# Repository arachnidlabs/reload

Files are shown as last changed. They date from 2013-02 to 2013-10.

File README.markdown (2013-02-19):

# Re:load #



Re:load is an adjustable dummy load with the following features:

 * No external power supply required - powered by the device under test.
 * Wide range of input voltages, from 3.3 to 30 volts.
 * Adjustable load from 0 to 3.5 amps (or 0 to 10 amps in the high current version)
 * Up to 14 watts power dissipation (40 watts in the high current version)
 * Virtually indestructible: The power FET, BTS117, has built in overtemp, ESD, and overcurrent protection. A diode protects the opamp from reverse bias.
 * Load remains constant under the whole range of input voltage.
 * Screw terminal and banana plug footprints.
 * Low BoM cost, and easy to solder thru-hole parts.
 * Test points for reading current with a voltmeter.
 
Read more about Re:load [here](http://www.arachnidlabs.com/reload/), buy the regular one [here](https://tindie.com/shops/arachnidlabs/reload-the-simple-robust-affordable-dummy-load/) and Epic Re:load [here](https://tindie.com/shops/arachnidlabs/epic-reload-the-simple-robust-powerful-adjustable-dummy-load/). Assembly and usage instructions can be found [here](http://www.arachnidlabs.com/reload/instructions.html).
 
## BoM ##

<table>
  <thead>
    <tr><th>Designation</th><th>Re:load Part</th><th>Epic Re:load part</th><th>Quantity</th></tr>
  </thead>
  <tr><th></th><td colspan="2">Re:load PCB</td><td>1</td></tr>
  <tr><th>Q1</th><td>BTS117 TO-220 MOSFET</td><td>BTS141 TO-220 MOSFET</td><td>1</td></tr>
  <tr><th></th><td>12 watt heatsink</td><td>20 watt heatsink</td><td>1</td></tr>
  <tr><th>R1</th><td colspan="2">3 watt 0.05 ohm resistor</td><td>1</td></tr>
  <tr><th>R6</th><td colspan="2">10k ohm potentiometer</td><td>1</td></tr>
  <tr><th>IC1</th><td colspan="2">MCP6002 8-DIP Op-Amp</td><td>1</td></tr>
  <tr><th>IC2</th><td colspan="2">LP2950 3.0v precision LDO regulator</td><td>1</td></tr>
  <tr><th>JP1</th><td colspan="2">2 terminal 5.0mm spring terminal</td><td>1</td></tr>
  <tr><th>D1</th><td colspan="2">BAT42 Schottky Diode</td><td>1</td></tr>
  <tr><th>C2</th><td colspan="2">33uF Electrolytic Capacitor</td><td>1</td></tr>
  <tr><th>C3</th><td colspan="2">1uF Ceramic Capacitor</td><td>1</td></tr>
  <tr><th>C1</th><td colspan="2">0.1uF Ceramic Capacitor</td><td>1</td></tr>
  <tr><th rowspan="3">R3</th><td colspan="2">510k ohm resistor</td><td>1</td></tr>
  <tr><td colspan="2">160k ohm resistor</td><td>1</td></tr>
  <tr><td colspan="2">75k ohm resistor</td><td>1</td></tr>
  <tr><th>R4, R5</th><td colspan="2">10k ohm 1% resistor</td><td>2</td></tr>
  <tr><th>R7</th><td colspan="2">100 ohm resistor</td><td>1</td></tr>
  <tr><th></th><td colspan="2">Packet of thermal paste</td><td>1</td></tr>
  <tr><th></th><td colspan="2">M3 6mm machine screw</td><td>1</td></tr>
  <tr><th></th><td colspan="2">M3 nut</td><td>1</td></tr>
</table>

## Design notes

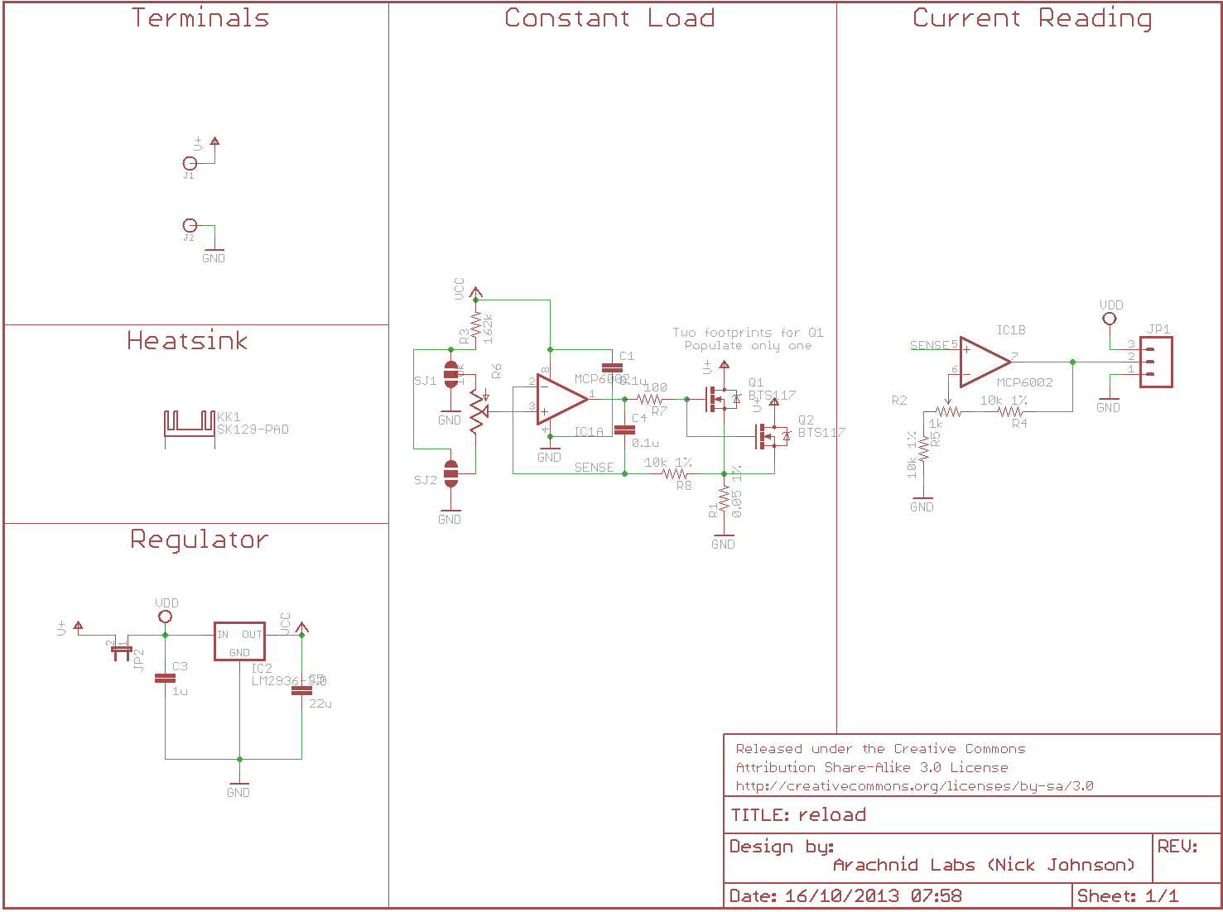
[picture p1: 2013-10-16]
reload-schematic.png

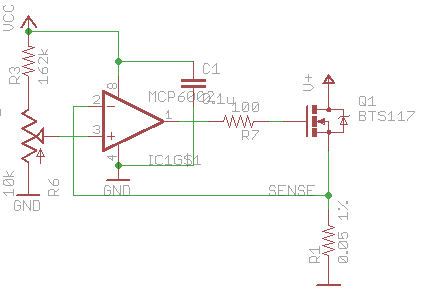
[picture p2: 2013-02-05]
reload-core-schematic.png

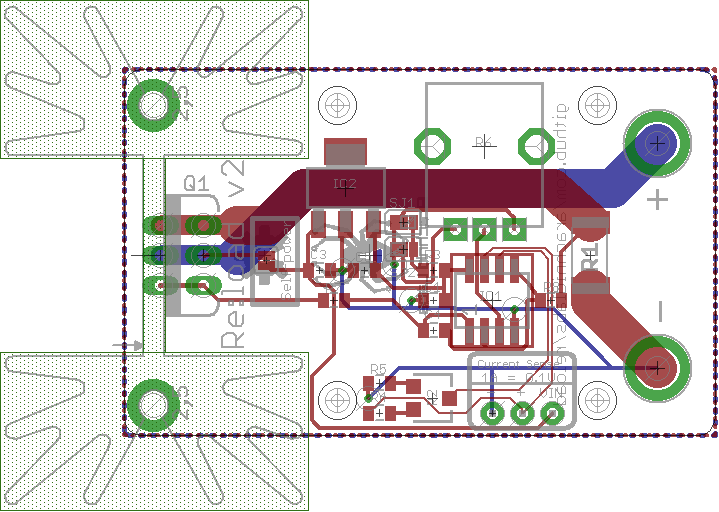
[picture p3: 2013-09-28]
reload-layout.png

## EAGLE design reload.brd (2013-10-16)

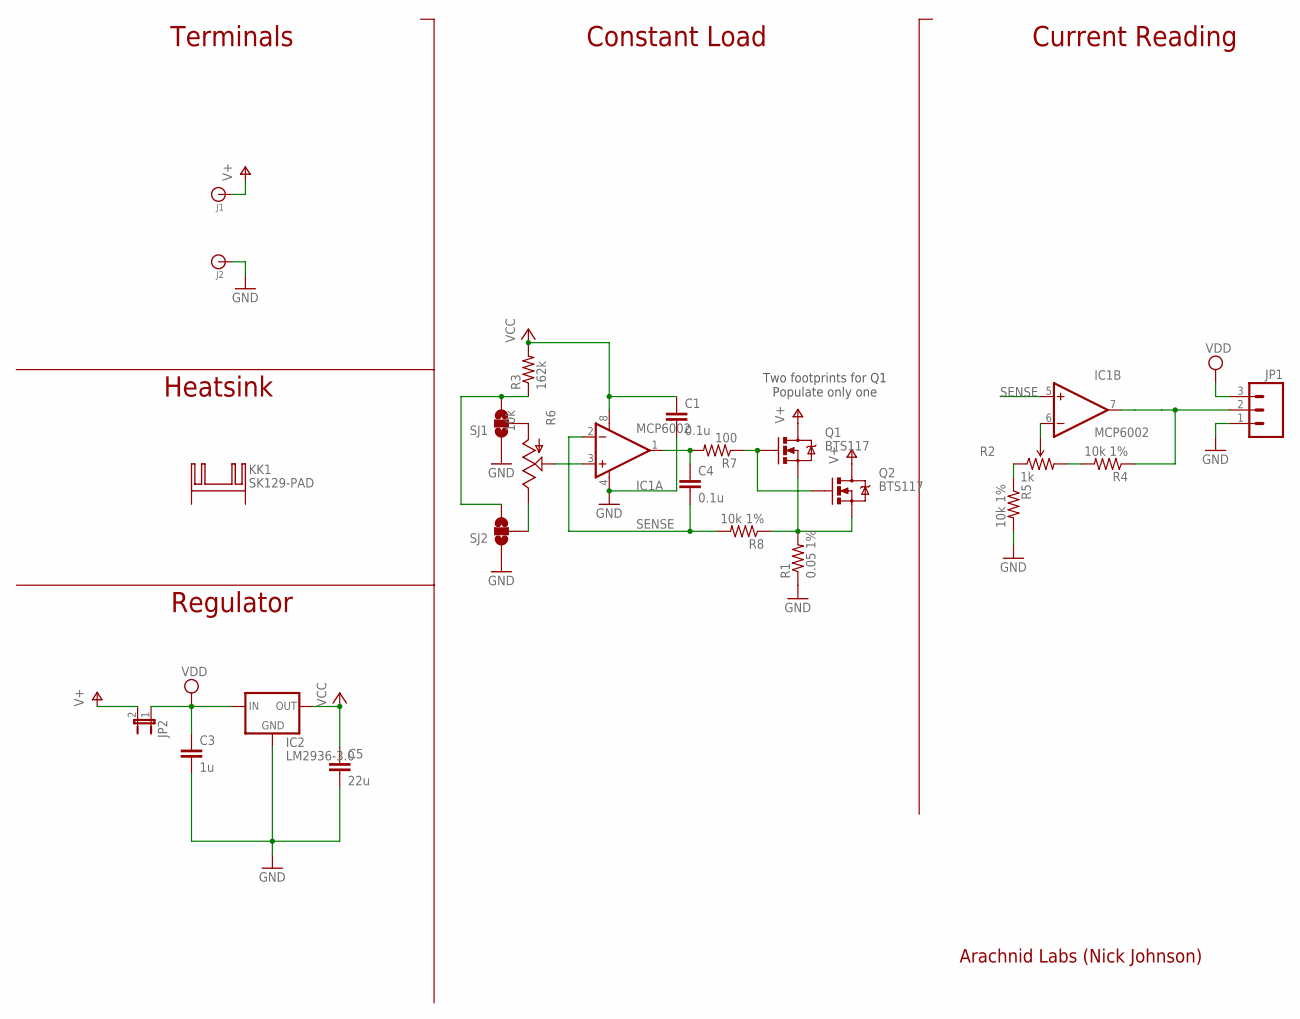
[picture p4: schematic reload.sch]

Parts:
C1, C4: 0.1u; 0805
C3: 1u; 0805
C5: 22u; 0805
IC1: MCP6002; SOP08
IC2: LM2936-3.0; SOT223
J1, J2: BANANA_CONN
JP1: M031X03_NO_SILK; 1X03_NO_SILK
JP2: JUMPER-2SMD-NC; SJ_2S
KK1: SK129-PAD; SK129
Q1: BTS117; TO220V
Q2: BTS117; TO220V-NOSILK
R1: 0.05 1%; R2512
R2: 1k; TRIMPOT-EVN5E
R3: 162k; 0805
R4, R5, R8: 10k 1%; 0805
R6: 10k; ALPS_POT
R7: 100; 0805
SJ1: SOLDERJUMPER_2WAYPASTE2&3; SJ_3_PASTE2&3
SJ2: SOLDERJUMPER_2WAYPASTE1&2; SJ_3_PASTE1&2

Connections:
GND: C1.2, C3.2, C5.2, IC1.4 (V-), IC2.2 (GND), J2.P$1, JP1.1, R1.1, R5.2, SJ1.1, SJ2.1
IREF: IC1.7 (OUT), JP1.2, R4.1
unnamed: C4.1, IC1.1 (OUT), R7.2
unnamed: R6.P$3 (A), SJ1.2
unnamed: Q1.3 (S), Q2.3 (S), R1.2, R8.1
unnamed: IC1.3 (+IN), R6.P$2 (S)
unnamed: IC1.6 (-IN), R2.2 (WIPER)
unnamed: R2.1 (CCW), R5.1
unnamed: R2.3 (CW), R4.2
unnamed: R6.P$1 (E), SJ2.2
unnamed: Q1.1 (G), Q2.1 (G), R7.1
unnamed: R3.1, SJ1.3, SJ2.3
SENSE: C4.2, IC1.2 (-IN), IC1.5 (+IN), R8.2
V+: J1.P$1, JP2.2, Q1.2 (D), Q2.2 (D)
VCC: C1.1, C5.1, IC1.8 (V+), IC2.3 (OUT), R3.2
VDD: C3.1, IC2.1 (IN), JP1.3, JP2.1

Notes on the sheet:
Terminals
Heatsink
Regulator
Constant Load
Current Reading
Arachnid Labs (Nick Johnson)
Two footprints for Q1 Populate only one

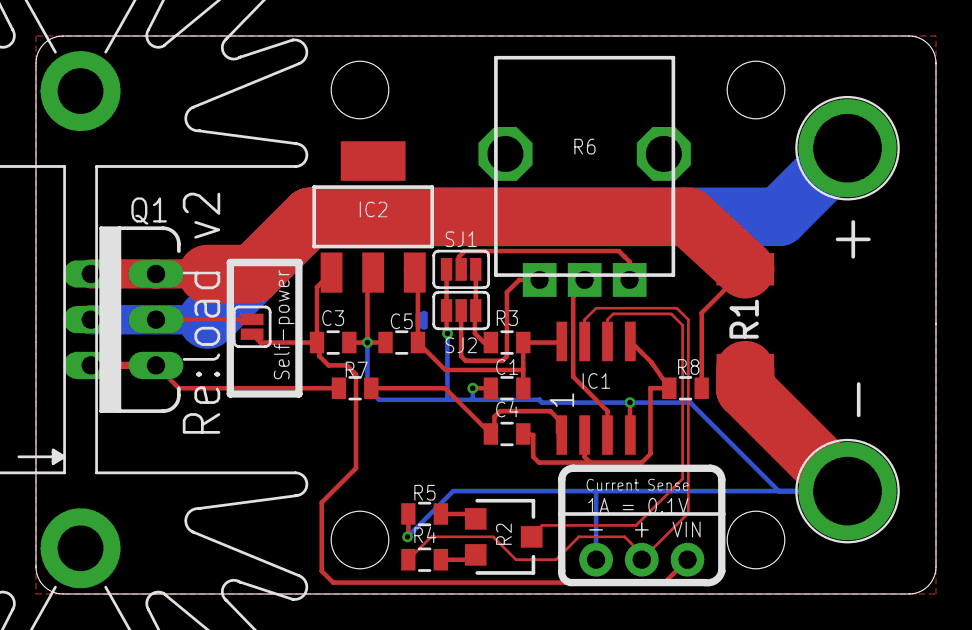
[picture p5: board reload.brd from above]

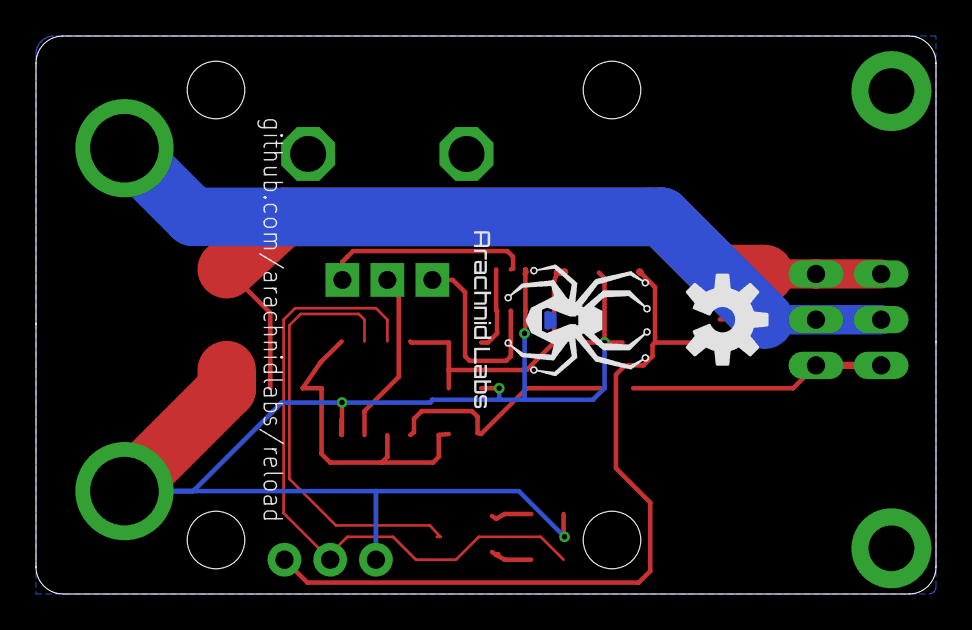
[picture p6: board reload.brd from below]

Board: 2 copper layers, 50.0 x 31.0 mm, 25 parts (2 on the bottom side), 16 nets.

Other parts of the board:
U$2: ARACHNID_LABS_LOGO_SM
U$3: OSHW-LOGO-M

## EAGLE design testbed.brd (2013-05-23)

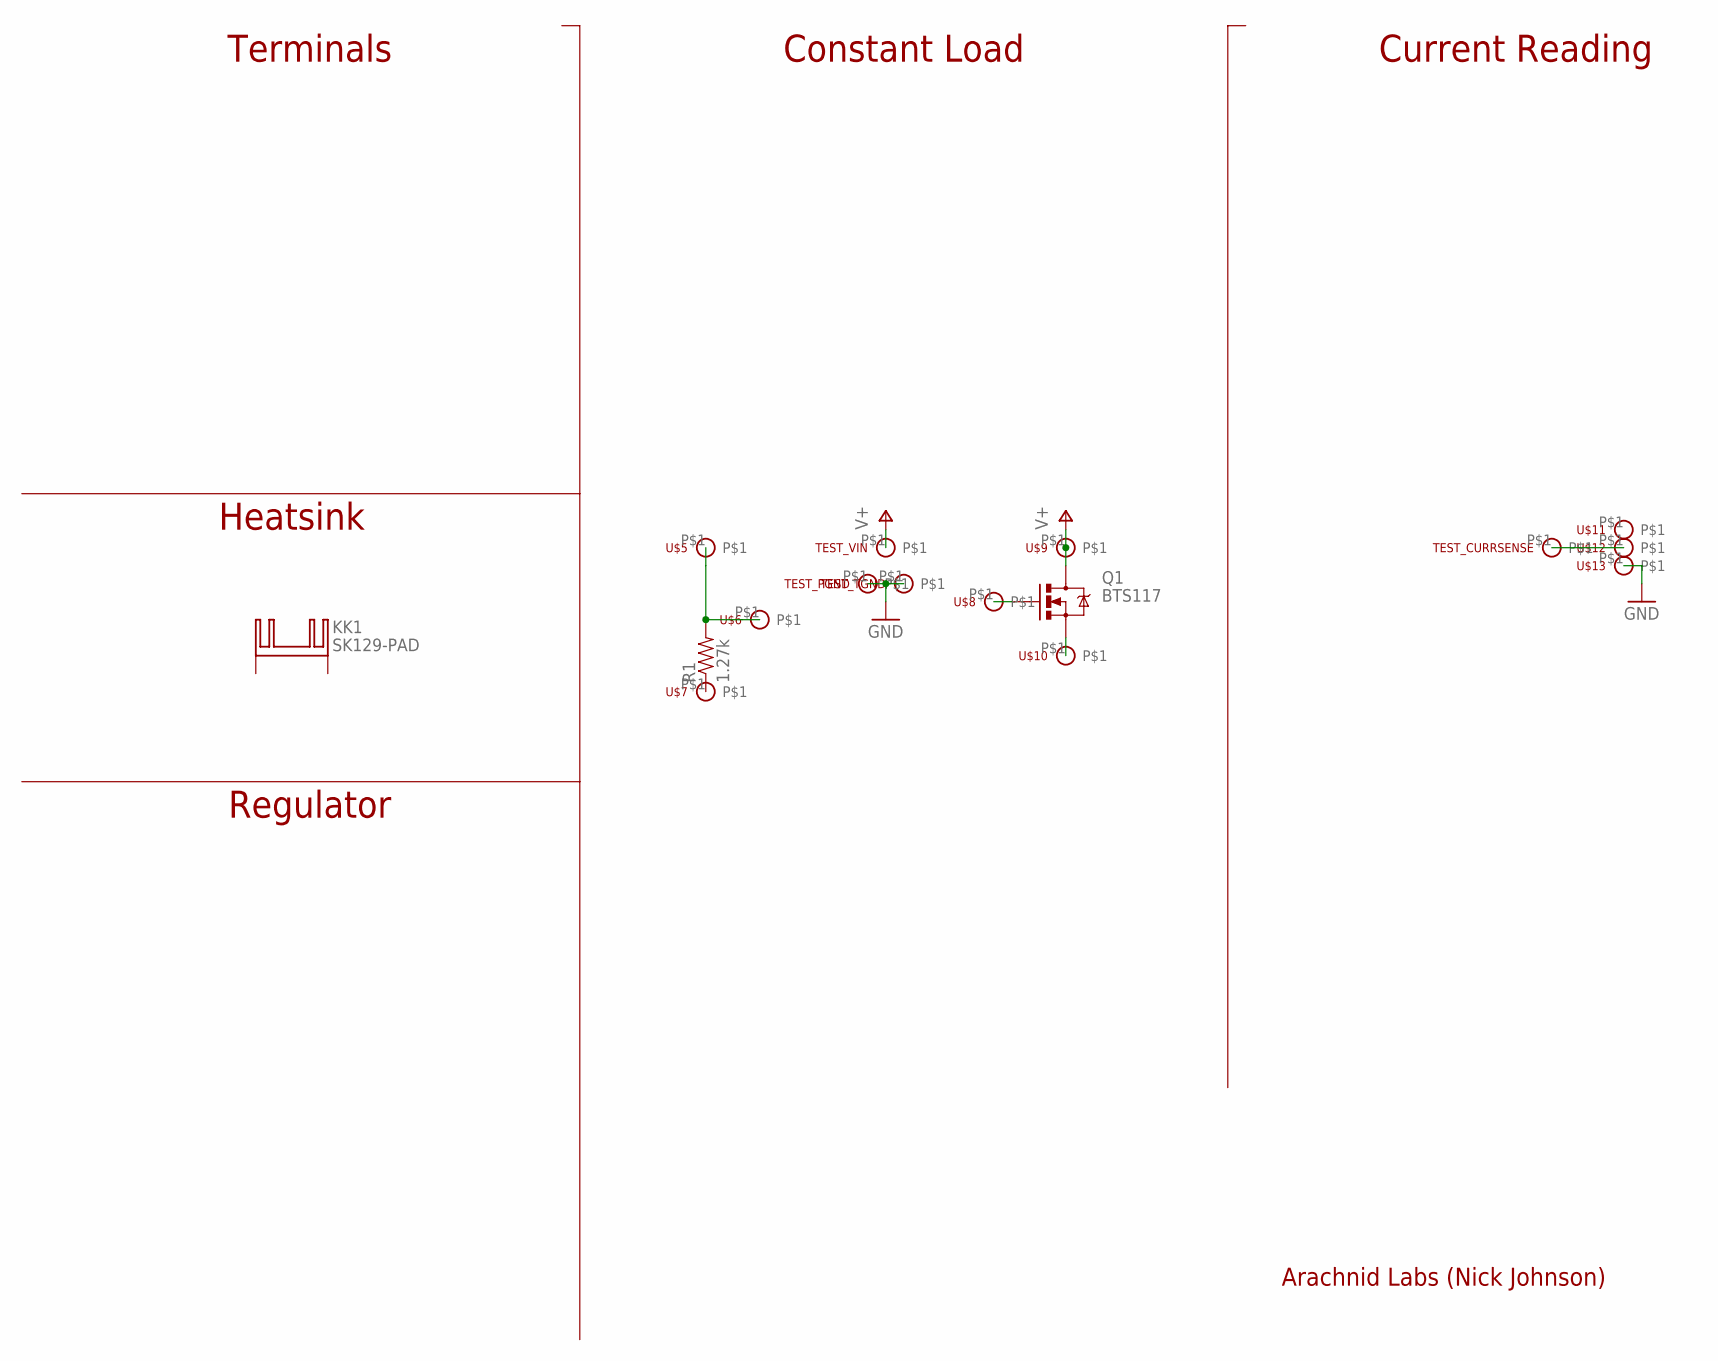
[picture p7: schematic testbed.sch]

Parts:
KK1: SK129-PAD; SK129
Q1: BTS117; TO220V
R1: 1.27k; 0805
TEST_CURRSENSE: TEST_POINT
TEST_PGND: TEST_POINT
TEST_TGND: TEST_POINT
TEST_VIN: TEST_POINT
U$5, U$6, U$7, U$8, U$9, U$10, U$11, U$12, U$13: POGOPIN1.02; POGOPIN-1.02

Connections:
GND: TEST_PGND.P$1, TEST_TGND.P$1, U$13.P$1
unnamed: Q1.1 (G), U$8.P$1
unnamed: TEST_CURRSENSE.P$1, U$12.P$1
unnamed: Q1.3 (S), U$10.P$1
unnamed: R1.2, U$5.P$1, U$6.P$1
unnamed: R1.1, U$7.P$1
V+: Q1.2 (D), TEST_VIN.P$1, U$9.P$1

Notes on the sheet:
Terminals
Heatsink
Regulator
Constant Load
Current Reading
Arachnid Labs (Nick Johnson)

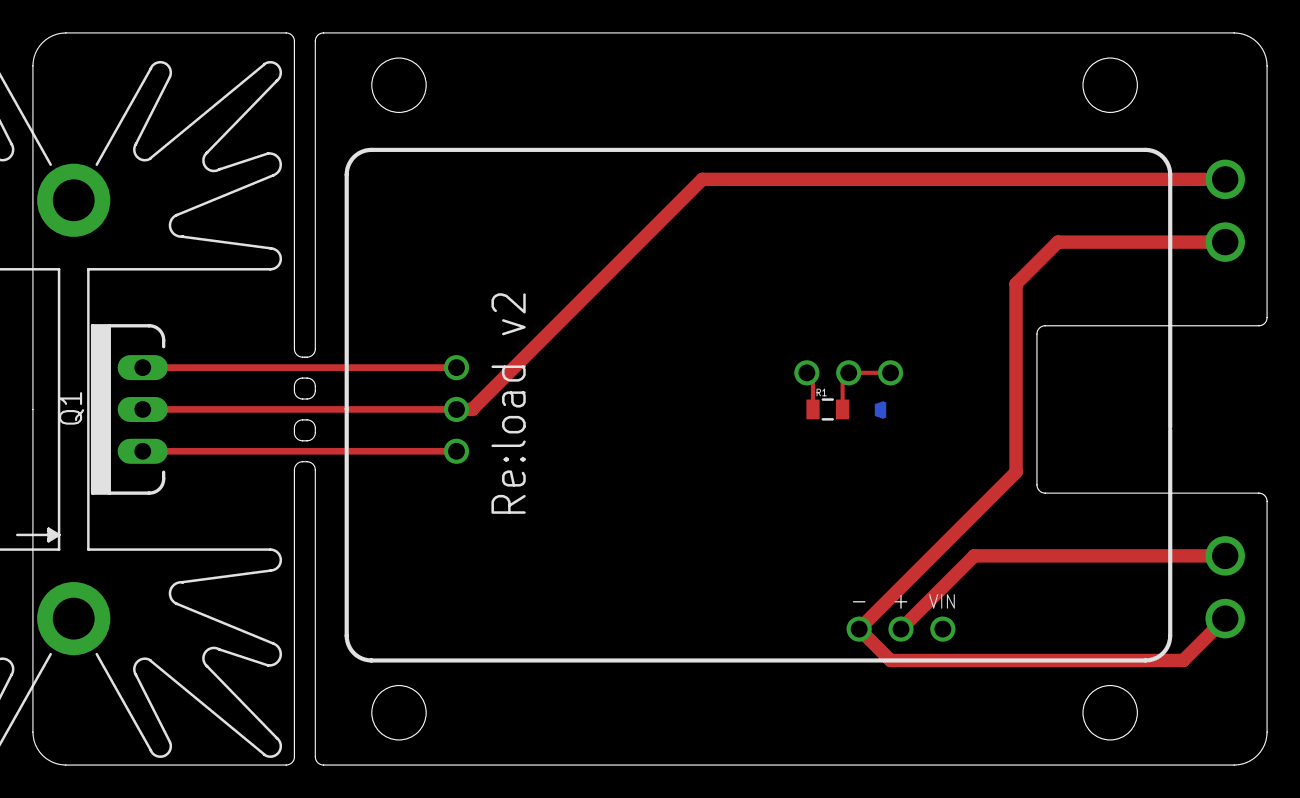
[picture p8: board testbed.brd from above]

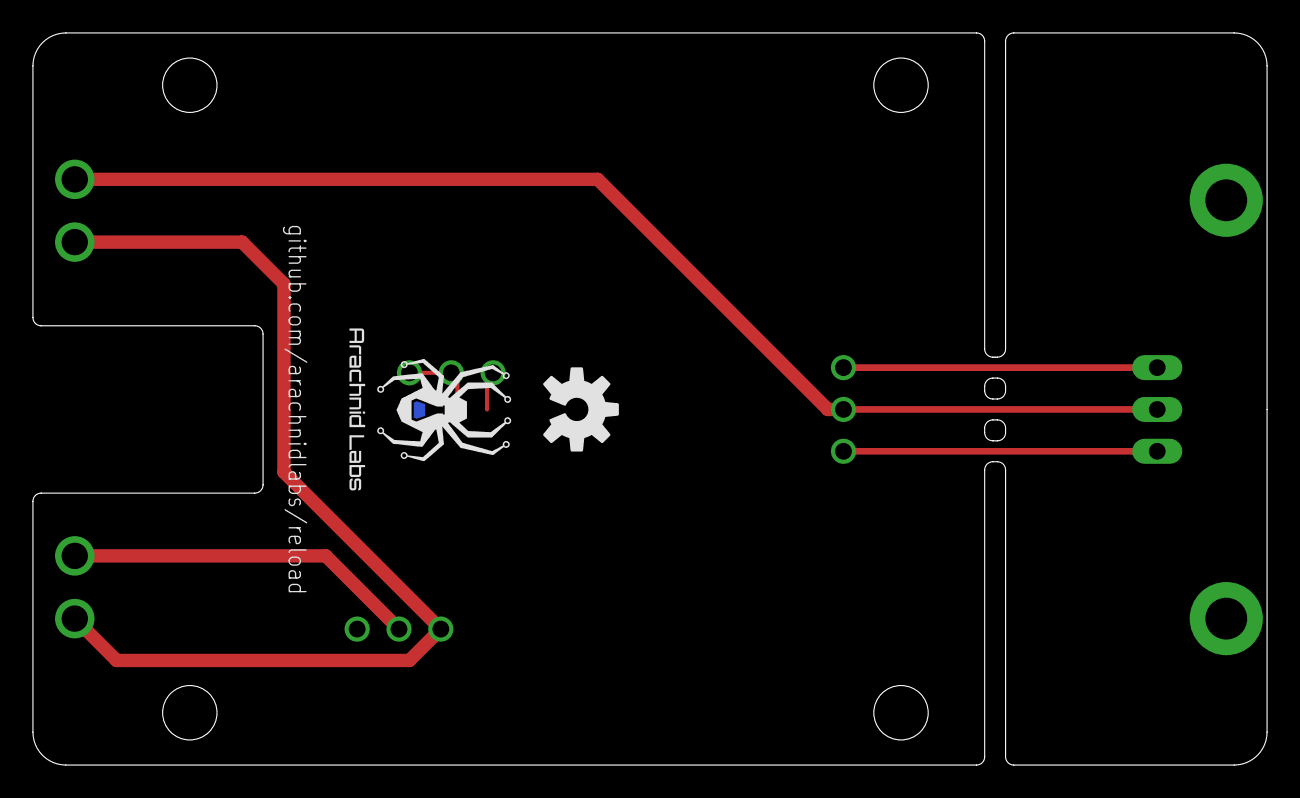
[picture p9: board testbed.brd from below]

Board: 2 copper layers, 74.9 x 44.5 mm, 22 parts (2 on the bottom side), 7 nets.

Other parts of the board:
U$1, U$4, U$14, U$15: STAND-OFF
U$2: ARACHNID_LABS_LOGO_SM
U$3: OSHW-LOGO-M

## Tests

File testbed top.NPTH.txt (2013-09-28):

%
M48
M72
T01C0.1300
%
T01
X2630Y1380
X19630Y1380
X19630Y16380
X2630Y16380
M30

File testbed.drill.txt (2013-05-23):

%
M48
M72
T01C0.0400
T02C0.0402
T03C0.0630
T04C0.1000
%
T01
X6850Y7600
X6850Y8600
X6850Y9600
T02
X14350Y9600
X14350Y8600
X14350Y7600
X22725Y9475
X23725Y9475
X24725Y9475
X24975Y3350
X23975Y3350
X25975Y3350
T03
X32725Y3600
X32725Y5100
X32725Y12600
X32725Y14100
T04
X5200Y3600
X5200Y13600
M30

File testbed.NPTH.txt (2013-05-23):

%
M48
M72
T01C0.1300
%
T01
X12975Y1350
X29975Y1350
X29975Y16350
X12975Y16350
M30

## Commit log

2013-01-05 Initial commit.
    [reload.brd, reload.sch]
2013-01-05 Updated schematic, layout tweak.
    [reload.brd]
2013-01-05 Generated gerbers; minor layout/schematic tweaks.
    [reload.brd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]
2013-01-06 Reworked to use a voltage regulator, added reverse protection diode, other improvements.
    [reload.brd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]
2013-01-06 Added trimpot on back side of board; minor other layout tweaks.
    [reload.brd, reload.sch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]
2013-01-06 Fix readme BoM list.
2013-01-06 Yet more BoM tweaks.
2013-01-06 Added a second BoM for 10A version.
    [reload.brd, reload.sch]
2013-01-07 Added series resistor for FET output.
    [reload.brd, reload.sch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]
2013-02-05 Tweaks to schematic.
    [reload.brd, reload.sch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]
2013-02-05 Improved schematic layout.
    [reload.brd, reload.sch]
2013-02-06 Board rearrangement for spring terminals, better pot placement.
    [reload.brd, reload.sch]
2013-02-06 Silkscreen tweaks.
    [reload.brd]
2013-02-06 More silkscreen changes, added logo.
    [reload.brd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]
2013-02-19 Tweaks to production version of reload
    [reload.brd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]
2013-04-01 SMD respin
    [reload.brd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]
2013-05-08 Respin with SMD parts
    [reload.brd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]
2013-05-23 Changes to SMD re:load v2; added test fixture
    [reload.back.gbl, reload.backmask.gbs, reload.backpaste.gbp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]
2013-05-25 Layout tweaks and updated images
    [reload.brd, reload.sch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]
2013-09-28 Tweaks and new Re:load images
    [reload.brd, reload.sch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]
2013-10-16 Added complete technical BoM and updated schematic as so politely suggested by a commenter
    [reload.brd, reload.sch]

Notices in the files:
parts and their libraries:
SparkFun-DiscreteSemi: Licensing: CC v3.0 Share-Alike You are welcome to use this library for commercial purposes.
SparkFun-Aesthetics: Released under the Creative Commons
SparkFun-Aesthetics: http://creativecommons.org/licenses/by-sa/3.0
